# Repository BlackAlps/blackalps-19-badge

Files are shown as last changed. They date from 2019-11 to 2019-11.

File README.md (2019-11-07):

# BlackAlps badge

This repository contains the blackAlps badge source, along with utilities to create user-created apps.

## Easy start

The easiest way is to use [Ampy](https://github.com/scientifichackers/ampy/tree/c0b568cf12b017bd9dfd7d61a7132b7d760278a0)
to store new files on the badge. To install on MacOS or GNU/Linux, simply type:

```bash
pip3 install --user adafruit-ampy
```

Once it's installed, on MacOS you can type the following to have a look at the
badge and to upload a new file:

```bash
ampy --port /dev/tty.usbserial-14410 ls
```

You can add the [template](utils/app_template/template.py) to the [apps](badgeOS/apps)
directory, and then upload it to the badge:

```bash
cp utils/app_template/template.py badgeOS/apps/myapp.py
ampy --port /dev/tty.usbserial-14410 put ./badgeOS/apps/myapp.py apps/myapp.py
```

Now you need to reset the board. The `ampy reset` doesn't seem to work, so you
need to remove and add the battery again.

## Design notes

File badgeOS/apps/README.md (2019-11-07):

# Apps directory

Here go the apps. In order to test the apps, you can use the `simulator.py`
file:

```bash
python3 simulator.py snake.py
```

The display is printed to the konsole, so chose a very tiny font. Currently it
supports the keys and the display, but not the Wifi.

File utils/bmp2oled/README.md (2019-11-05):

# bmp2oled

This script converts a bitmap image to a byte array to be displayed on the OLEd screen.

## Dependancies

This script needs pyGame to be used :

```
pip install pygame
```

## Usage

Create the bytearray with bmp2oled :
```
python3 bmp2oled.py <image>
```

Then, use this sample code to display the image on the screen :
```
import framebuf

byte_array = <bmp2oled output>

width = 128
height = 64

oled.fill(0)
fb = framebuf.FrameBuffer(byte_array,width ,height , framebuf.MVLSB)
oled.blit(fb, 0,0)
oled.show()
```

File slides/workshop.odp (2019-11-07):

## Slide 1

Hacking the badge

## What ?

- Based on ESP32
  - Dual 240MHz core
  - Wi-Fi / Bluetooth
- OLED screen
  - I2C connection
- 5 buttons

## Firmware

- Firmware is based on Micropython
- Python for microcontrollers
- http://docs.micropython.org/en/latest/

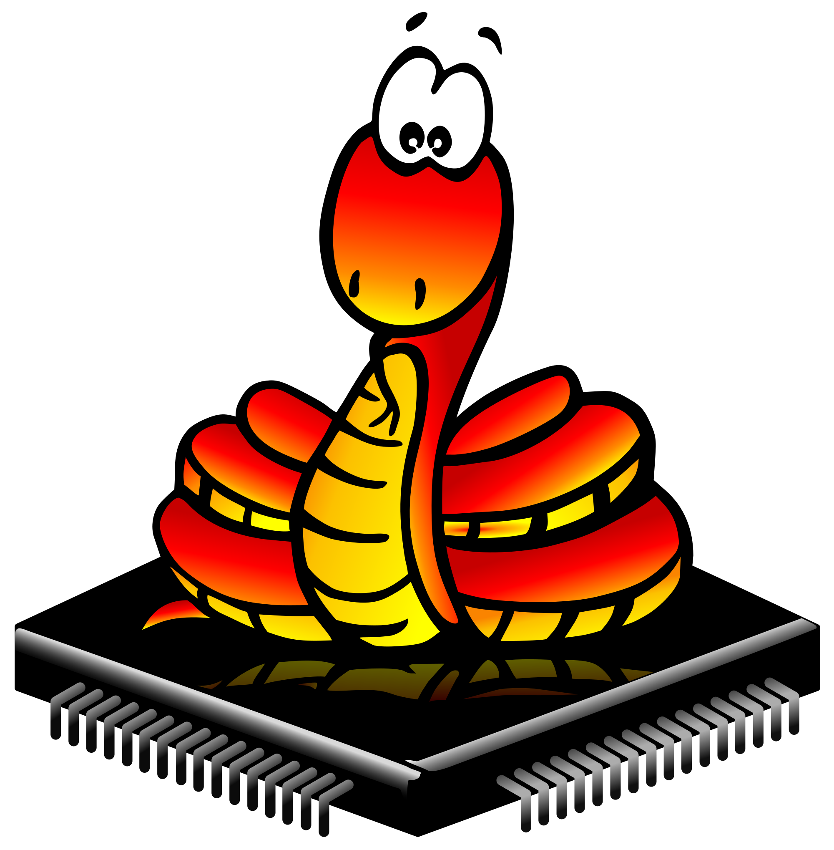
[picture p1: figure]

## BadgeOS

- Custom Python « OS » made for the badge
- Provides APIs to interact with the badge features
- Allows to easily add user-created « apps »

## Workshop

- Discover the basic API, based on the existing apps
- For beginners : Create an analog clock
- For pros : Create your own app

## Connecting to the badge

- Connect the USB cable
- A serial port should be detected
  - On Windows, might need to install ch340 driver
  - On GNU/Linux, you might need to disable ModemManager
- Use screen to connect (Putty on Windows)
  - $ screen <serial> 115200

## Access the REPL

- Press <ctrl+c> several times to access the Python shell
- Able to interact with the badge from here

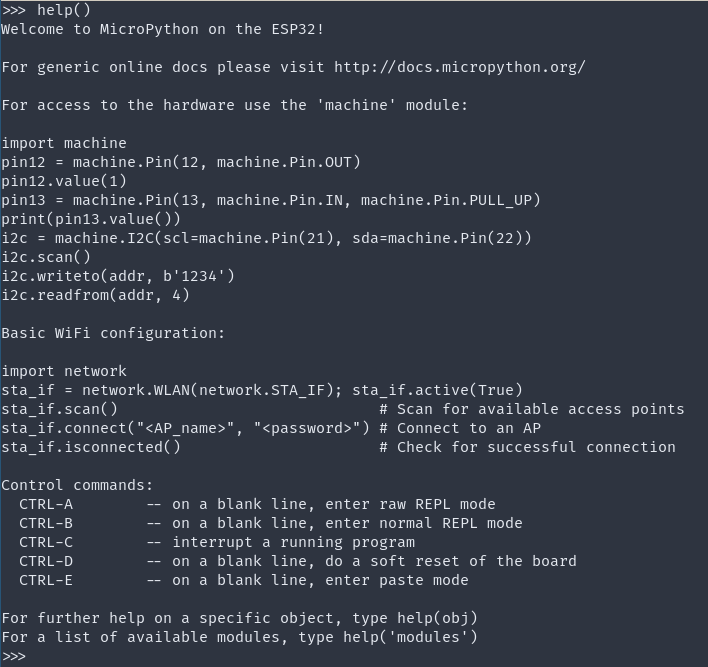
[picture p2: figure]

## “SDK”

- Clone the badge github repo
  - https://github.com/Baldanos/blackalps-19-badge
  - Don’t forget to fetch the submodules
- Contains the full badge source

## Testing code

- Using the REPL, it’s easy to test some features interactively
- The badge instance is in the BADGE variable

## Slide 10

BadgeOS API

## Main functions

- BADGE.prompt(prompt)
  - Prompts the user for text, returns the input text
- BADGE.menu([items])
  - Displays a menu, returns the selected item
- BADGE.show_text(text)
  - Displays a text on the screen, with scrolling and wrapping

## Screen API

- BADGE.screen.text(text)
  - Show text on the screen
- BADGE.screen.textbox([text])
  - Show a textbox with the text (one item per line)
- BADGE.screen.show_logo()
  - Show the BlackAlps logo

## Buttons API

- BADGE.buttons.wait_button()
  - Blocking
  - Wait for a button press, returns the pressed button
- BADGE.buttons.get_button()
  - Non-blocking
  - Returns the pressed button, None otherwise

## Internet API

- BADGE.net.online()
  - Connect to the WiFi
- BADGE.net.offline()
  - Disconnect the WiFi
- BADGE.net.add_callback(topic, function)
  - Add a callback on MQTT topic
- BADGE.net.client.check_msg()
  - Check for new messages on the MQTT topics

## Screen

- Uses an SSD1306 OLED controller
- Resolution is 128x64 pixels, two colors
- Micropython has a framebuffer support with drawing primitives
  - https://docs.micropython.org/en/latest/library/framebuf.html
  - Accessible in BADGE.screen.oled

## Screen - cont

- The screen does not get refreshed until you ask for it
  - Use BADGE.screen.oled.show() to refresh the screen
  - Refreshing the screen takes a lot of time, try to draw everything before refreshing the screen

## Screen -Exercises

- Clear the screen
- Write “Hello world !” on the screen

>>> BADGE.screen.clear()

>>> BADGE.show_text("Hello world !")

## Buttons

- The badge provides 5 buttons
- Button presses are triggered with interrupts

Button | GPIO
UP | 32
DOWN | 33
LEFT | 34
RIGHT | 35
ENTER | 18

## Buttons - Exercises

- Create a loop that prints which button is pressed on the screen

>>> while(True):

... btn = BADGE.buttons.wait_button()

... BADGE.screen.textbox([btn])

## Internet

- The badge is connected to the Internet
  - WiFi credentials are stored in the settings.py file
- See schedule.py in apps/ for an example

## Adding apps

- On the badge, every .py file stored in the apps/ directory will be loaded as an app
- Use the template file provided in the repo to see how it works

## Adding apps – cont.

- Use ampy.py to push files on the badge
  - Badge has to be in REPL mode
  - You have to quit screen to allow ampy to push files
    - <ctrl+a>K
- $ python3 ampy.py -p <serial> put <src> <dst>

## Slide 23

Analog clock

## Analog clock

- Create an analog clock
- Use the provided template to prepare your app

## Analog clock – Sync time

- ESP32 has an internal RTC
  - Has to be set at each reboot
  - https://docs.micropython.org/en/latest/esp32/quickref.html#real-time-clock-rtc
- Call a public time API to get current time
  - $ curl "http://worldtimeapi.org/api/timezone/Europe/Zurich"

## Analog clock – Clock face

- Draw the clock face
  - Place 12 dots around the center of the screen
- Use sinus / cosinus to calculate the placement of the dots
  - Note : In Python, the angle is given in radians

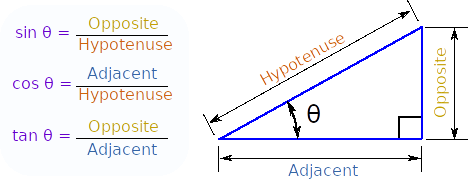
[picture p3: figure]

## Solution

import math

p = 360/12

BADGE.screen.clear()

for i in range(12):

x = 64+int(30*math.cos(math.radians(p*i)))

y = 32+int(30*math.sin(math.radians(p*i)))

BADGE.screen.oled.pixel(x,y,1)

BADGE.screen.oled.show()

## Analog clock - Hands

- Draw the hands
  - Draw a line from the center to a specific point
    - self.badge.screen.oled.line(x1,y1, x2, y2, c)
  - Calculate the coordinates using sinus/cosinus
- Adding the seconds hand is optional

## Analog clock - Update

- As the app controls the badge, you need to run it in an infinite loop
- Draw the clock, then wait for a minute (or a second) to draw the screen again.

## Analog clock - Quit

- Add a feature to quit the app when the user presses the ENTER button

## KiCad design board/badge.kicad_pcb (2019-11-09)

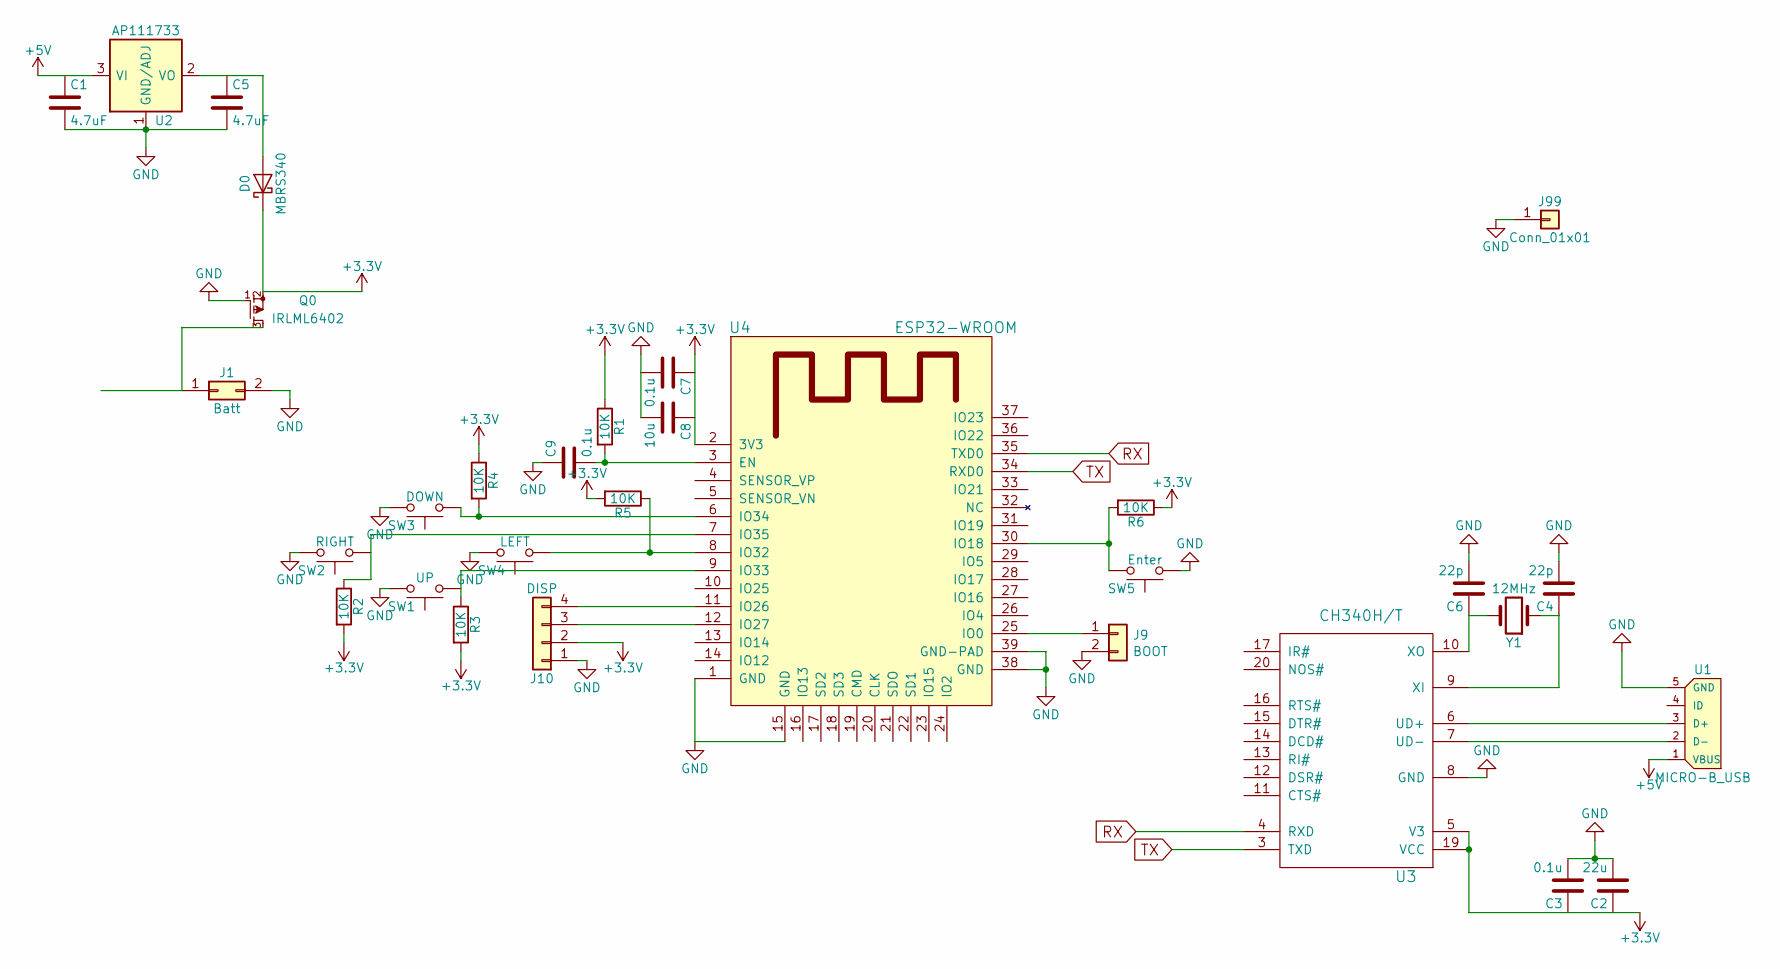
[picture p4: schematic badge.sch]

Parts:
C1, C5: 4.7uF; C_0805
C2: 22u; C_0805
C3, C7, C9: 0.1u; C_0805
C4, C6: 22p; C_0805
C8: 10u; C_0805
D0: MBRS340; D_SMC
J1: Batt; Pin_Header_Straight_1x02_Pitch2.54mm
J9: BOOT; Pin_Header_Straight_1x02_Pitch2.54mm
J10: DISP; Pin_Header_Straight_1x04_Pitch2.54mm
J99: Conn_01x01; 1pin
Q0: IRLML6402; SOT-23
R1, R2, R3, R4, R5, R6: 10K; R_0805
SW1: UP; SW_SPST_FSMSM
SW2: RIGHT; SW_SPST_FSMSM
SW3: DOWN; SW_SPST_FSMSM
SW4: LEFT; SW_SPST_FSMSM
SW5: Enter; SW_SPST_FSMSM
U1: MICRO-B_USB
U2: AP111733; SOT-223
U3: CH340H/T; SSOP-20_5.3x7.2mm_Pitch0.65mm
U4: ESP32-WROOM
Y1: 12MHz; NX5032GA-12.000000MHZ-LN-CD-1

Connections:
+3V3: D0.1 (K), J10.2, Q0.2 (S), R1.1, R2.2, R3.2, R4.1, R5.2, R6.1, U3.5 (V3), U3.19 (VCC), U4.2 (3V3)
+5V: U1.1 (VBUS), U2.3 (VI)
GND: C1.2, C2.2, C3.2, C4.2, C5.2, C6.2, C8.2, C9.1, J1.2, J9.2, J10.1, J99.1, Q0.1 (G), SW1.2, SW2.2, SW3.2, SW4.2, SW5.1, U1.5 (GND), U2.1 (GND/ADJ), U3.8 (GND), U4.1 (GND), U4.15 (GND), U4.38 (GND), U4.39 (GND-PAD)
unnamed: C4.1, U3.9 (XI), Y1.1
unnamed: C6.1, U3.10 (XO), Y1.2
unnamed: C9.2, R1.2, U4.3 (EN)
unnamed: D0.2 (A), U2.2 (VO), U2.4 (VO)
unnamed: J1.1, Q0.3 (D)
unnamed: J9.1, U4.25 (IO0)
unnamed: J10.3, U4.12 (IO27)
unnamed: J10.4, U4.11 (IO26)
unnamed: R2.1, U4.7 (IO35)
unnamed: R3.1, U4.9 (IO33)
unnamed: R4.2, SW3.1, U4.6 (IO34)
unnamed: R5.1, SW4.1, U4.8 (IO32)
unnamed: R6.2, SW5.2, U4.30 (IO18)
unnamed: U1.2 (D-), U3.7 (UD-)
unnamed: U1.3 (D+), U3.6 (UD+)
RX: U3.4 (RXD), U4.35 (TXD0)
TX: U3.3 (TXD), U4.34 (RXD0)

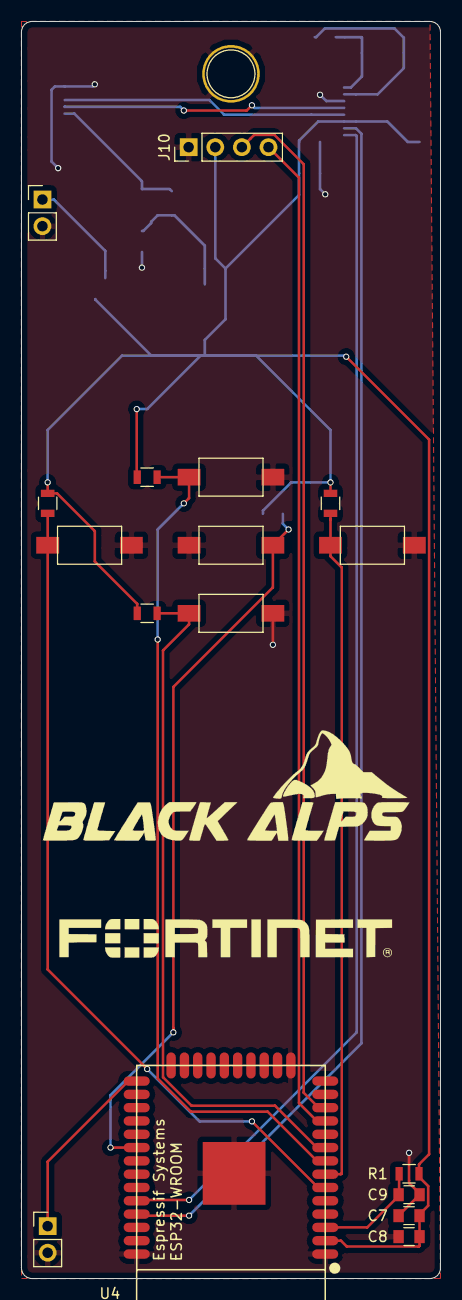
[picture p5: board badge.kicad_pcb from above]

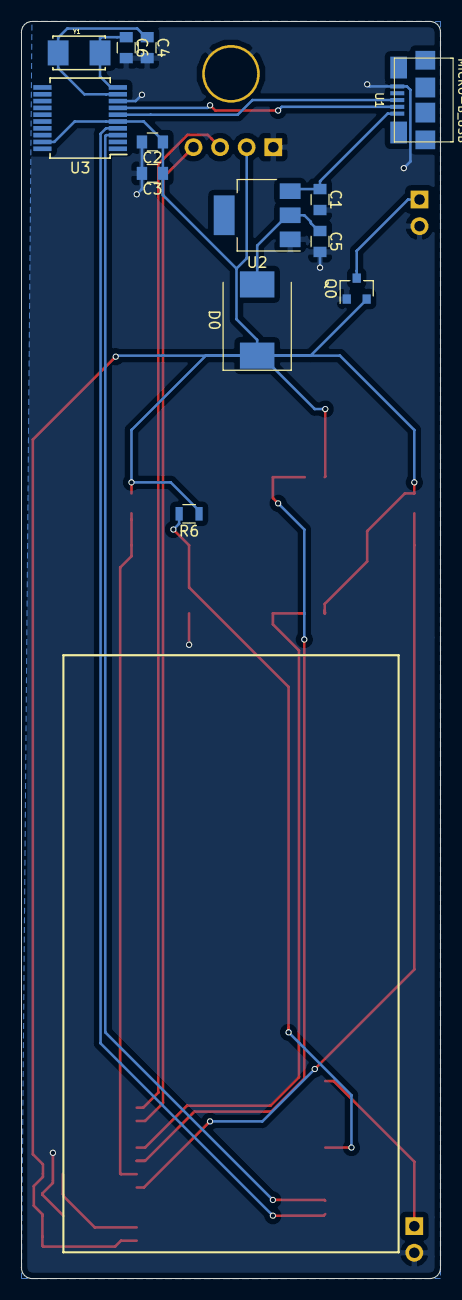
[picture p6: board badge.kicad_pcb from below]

Board: 2 copper layers, 40.0 x 120.0 mm, 31 parts (13 on the bottom side), 20 nets.

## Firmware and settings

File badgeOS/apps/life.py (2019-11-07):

#!/usr/bin/env python3
import time
import random


class App:

    def __init__(self, badge):
        self.badge = badge
        self.NAME = "Life"
        self.board = Board(badge, 16)

    def run(self):
        while self.badge.buttons.get_button() == None:
            self.badge.screen.textbox(["The game of life", "Keys spawn figures", "Enter quits", "Down clears"])

        self.board.clear()
        self.add_glider(5, 5)
        while True:
            self.board.print()
            key = self.badge.buttons.get_button()
            if key == "ENTER":
                return
            if key == "LEFT":
                self.add_glider()
            if key == "RIGHT":
                self.add_cross()
            if key == "UP":
                self.add_tub()
            if key == "DOWN":
                self.board.clear()
            self.evolve()

    def getRand(self, width, height):
        return random.randrange(self.board.sizex - width), random.randrange(self.board.sizey - height)

    def evolve(self):
        newBoard = Board(self.badge, self.board.sizey)
        for x in range(self.board.sizex):
            for y in range(self.board.sizey):
                neighbors = self.board.neighbors(x, y)
                if neighbors < 2:
                    newBoard.set(x, y, 0)
                if neighbors == 2:
                    newBoard.set(x, y, self.board.cells[x][y])
                if neighbors == 3:
                    newBoard.set(x, y, 1)
                if neighbors > 3:
                    newBoard.set(x, y, 0)
        self.board = newBoard

    def add_glider(self, x=-1, y=-1):
        if x < 0 and y < 0:
            x, y = self.getRand(3, 3)
        self.board.set(x + 1, y, 1)
        if random.randrange(2) == 0:
            self.board.set(x, y + 1, 1)
        else:
            self.board.set(x + 2, y + 1, 1)
        self.board.set(x, y + 2, 1)
        self.board.set(x + 1, y + 2, 1)
        self.board.set(x + 2, y + 2, 1)

    def add_cross(self, x=-1, y=-1):
        if x < 0 and y < 0:
            x, y = self.getRand(3, 3)
        self.board.set(x, y, 1)
        self.board.set(x, y + 1, 1)
        self.board.set(x, y + 2, 1)

    def add_tub(self, x=-1, y=-1):
        if x < 0 and y < 0:
            x, y = self.getRand(3, 3)
        self.board.set(x + 1, y, 1)
        self.board.set(x, y + 1, 1)
        self.board.set(x + 2, y + 1, 1)
        self.board.set(x + 1, y + 2, 1)


class Board:

    def __init__(self, badge, size):
        self.badge = badge
        self.sizex = size * 2
        self.sizey = size
        self.mul = int(64 / size)
        self.cells = [[0]]
        self.clear()

    def clear(self):
        self.cells = [[0] * self.sizey for i in range(self.sizex)]

    def print(self):
        self.badge.screen.oled.fill(0)
        self.badge.screen.oled.rect(0, 0, 128, 64, 1)
        for x in range(self.sizex):
            for y in range(self.sizey):
                if self.cells[x][y] > 0:
                    posx = x * self.mul
                    posy = y * self.mul
                    for i in range(self.mul):
                        self.badge.screen.oled.hline(posx, posy + i, self.mul, 1)
        self.badge.screen.oled.show()

    def set(self, x, y, v):
        if x < 0 or x >= self.sizex:
            print("oob", x, y)
            return
        if y < 0 or y >= self.sizey:
            print("oob", x, y)
            return
        self.cells[x][y] = v

    def neighbors(self, cx, cy):
        count = 0
        for x in range(cx - 1, cx + 2):
            for y in range(cy - 1, cy + 2):
                if x != cx or y != cy:
                    if self.cells[x % self.sizex][y % self.sizey] > 0:
                        count = count + 1
        return count


def test_nb():
    b = Board(0, 4)
    b.set(0, 0, 1)
    print(b.neighbors(0, 0))
    print(b.neighbors(1, 1))
    print(b.neighbors(7, 3))
    print(b.neighbors(7, 2))
    print(b.neighbors(7, 1))


if __name__ == "__main__":
    test_nb()

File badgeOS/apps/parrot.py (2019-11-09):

import machine
import ssd1306
import framebuf

class App:

    def __init__(self, badge):
        self.badge = badge
        self.NAME = "Party Parrot"

    def run(self):
        frames = [
            bytearray(b'\x00\x00\x00\x00\x00\x00\x00\x00\x00\x00\x00\x00\x00\x00\x00\x00\x00\x00\x00\x00\x00\x00\x00\x00\x00\x00\x00\x00\x00\x00\x00\x00\x00\x00\x00\x00\x00\x00\x00\x00\x00\x00\x00\x00\x00\x00\x00\x00\x00\x00\x00\x00\x00\x00\x00\x00\x00\x00\x00\x80\x80\xc0\xe0\xe0\xf0\xf8\xfc\xfc\xfc\xfc|<<<<<\x1c\x18\x18\x18\x1c<<<<||<\x18\x18\x18<<|\xfc\xfc\xfc\xfc\xf8\xe0\x00\x00\x00\x00\x00\x00\x00\x00\x00\x00\x00\x00\x00\x00\x00\x00\x00\x00\x00\x00\x00\x00\x00\x00\x00\x00\x00\x00\x00\x00\x00\x00\x00\x00\x00\x00\x00\x00\x00\x00\x00\x00\x00\x00\x00\x00\x00\x00\x00\x00\x00\x00\x00\x00\x00\x00\x00\x00\x00\x00\x00\x00\x00\x00\x00\x00\x00\x00\x00\x00\x00\x00\x00\x00\x00\x80\x80\x80\xc0\xe0\xf0\xf0\xf8|\x1c\x1e\x1f\x07\x07\x07\x03\x03\x01\x01\x00\x00\x00\x08\x1c\x1c<\xfc\xfc\xfc\xfc<\x1c\x1c\x1c\x1c\x1c\x1c\x1c\x1c\x1c\x1c\x1c\x1c\x1c\x08\x00\x00\x00\x00\x00\x00\x00\x00\x00\x0e<<<\xbc\x9c\x80\x80\x80\x00\x00\x00\x00\x00\x00\x00\x00\x00\x00\x00\x00\x00\x00\x00\x00\x00\x00\x00\x00\x00\x00\x00\x00\x00\x00\x00\x00\x00\x00\x00\x00\x00\x00\x00\x00\x00\x00\x00\x00\x00\x00\x00\x00\x00\x00\x00\x00\x00\x00\x00\x00\x00\x00\x00\x00\x00\x00\x00\x00\x00`\xf0\xf0\xf0s\x07\x07\x07\x03\x00\x00\x00\xe0\xf0\xf0\xf8\xfc\xfc\xfc\xfc\xfc\xfc\xf8\xf0\xf0\xf0\xe0\xe0\xf0\xf0\xff\xff\xff\xff\x00\x00\x00\x00\x00\xf8\xfc\xfc\xff\xff\xff\xff\xff\xff\x9c\x9c\x08\x00\x00\x00\x00@\xe0\xf0\xe0\xe0\x80\x80\x03\x07\x07\x07\xf7\xf0\xf0\xf0`\x00\x00\x00\x00\x00\x00\x00\x00\x00\x00\x00\x00\x00\x00\x00\x00\x00\x00\x00\x00\x00\x00\x00\x00\x00\x00\x00\x00\x00\x00\x00\x00\x00\x00\x00\x00\x00\x00\x00\x00\x00\x00\x00\x00\x00\x00\x00\x00\x00\x00\x80\xc0\xc0\xe8\xfe~~~<\x00\x00\x00\x80\x80\xc0\xfc\xfe\xfe\xfe\xff\xff\xff\xff\xff\xff\xff\xff\xff\xff\xff\xff\xff\xff\xff\xff\xff\xff\xff\xff\xff\xff\x00\x00\x00\x00\x00??\x7f\xff\xff\xff\xff\xff\x0f\x0f\x0f\x0f\x00\x80\x80\xc0\xc0\xff\xff\xff\xff\xff\xff\xff\x00\x00\x00\x00\x00\x010\xfe\xfe\xfe\xfe|\x00\x00\x00\x00\x00\x00\x00\x00\x00\x00\x00\x00\x00\x00\x00\x00\x00\x00\x00\x00\x00\x00\x00\x00\x00\x00\x00\x00\x00\x00\x00\x00\x00\x00\x00\x00\x00\x00\x00\x00\x00\x00\x80\xc0\xc0\xc0\xcf\x0f\x0f\x0f\x0f\x00\x00\x00\x00\x00\x00;?\x7f\x7f\xff\xff\xff\xff\xff\xff\xff\xff\xff\xff\xff\xff\xff\xff\xff\xff\xff\xff\xff\xff\xff\xff\xff\xff\xff\xff\xc0\xc0\xc0\x80\x00\x00\x00\x00\x07\x07\x03\x01\x01\x00\x00\x00\x00\x00\xf1\xf1\xf3\xff\xff\xff\xff\xff\xff\xff\xff\x1f\x0e\x0e\x04\x00\x00\x00\xc0\xe4\xe4\xc0\x80\x00\x00\x00\x00\x00\x00\x00\x00\x00\x00\x00\x00\x00\x00\x00\x00\x00\x00\x00\x00\x00\x00\x00\x00\x00\x00\x00\x00\xc0\xc0\xc0\xc0\xc0\xc0\xe0\xf0xx<>\x0e\x0f\x0f\x87\xc3\xc1\xc1\xc0\xc0\xe0\xfc\xfe\xfe\xfe\xfe\xfe\xfe\xfc\x00\x00\x00\x1f?????????\x7f\xff\xff\xff\xff\xff\xff\xff\xff\xff\xff\xff\xff\xff\xff\xff\xff\xff\xff\xff\xff\xfe\xfe\xfc\xf8\xf8\xf8\xf8\xf8\xf8\xfc\xfe\xfe\xff\xff\xff\xff\xff\xff\xff\xff\xff???\x00\x00\x00\xc0\xe0\xf0\xe7\xcf\x0f\x0f\x0f\x07\x00\x00\x00\x00\x00\x00\x00\x00\x00\x00\x00\x00\x00\x00\x00\x00\x00\x00\x00\x00\xc0\xe0\xe0\xe0\xeeO\x1f\x0f\x0f\x07\x03\x03\x01\x01\x01\xf1\xf8\xf8\xf8\xf8\xf8\xf8\xfc\xff\xff\xff\xff\xff\xff\xff\xff\xff\xff\xff\xff\xff\xff\xff\xff\xff\xff\xff\xfe\xfe\xfe\xfc\xf8\xf8\xf8\xf8\xf8\xf8\xf8\xf9\xf9\xf9\xf9\xf9\xf9\xff\xff\xff\xff\xff\xff\xff\xff\xff\xff\xff\xff\xff\xff\xff\xff\xff\xff\xff\xff\xff\xff\xff\xff\xff\xff\xff\xff\xff\xff\xff\xff\xff\xff\xef\xc6\xc6\x00\x00\x00\xff\xff\xff\xff\xff\x00\x00\x00\x00\x00\x00\x00\x00\x00\x00\x00\x00\x00\x00\x00\x00\x00\xf8\xf8\xfc\xfc\xff\xff\x0f\x0f\x07\x01\x01\x00\x00\x00\x00\x1e\x1f??????\x1f\x1f\x1f\x1f\x1f\x1f?\x1f???????\x1f\x1f\x1f????\x1f\x1f????????\x1f\x1f\x1f\x1f??????\x1f\x1f\x1f\x1f\x1f??????\x1f\x1f\x1f\x1f\x1f?????\x1f?????\x1f\x1f\x1f\x1f????=8\x18\x00\x00\x00\x01\x03\x03\x03\x01\x00\x00\x00\x00\x00\x00\x00\x00\x00\x00\x00\x00\x00\x00'),
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

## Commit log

2019-11-07 Adding instructions for first-timers
2019-11-07 add two apps: one with pico le croco, the other to vote for my talk
2019-11-09 Add board schematics
    [badge.kicad_pcb, badge.sch]
